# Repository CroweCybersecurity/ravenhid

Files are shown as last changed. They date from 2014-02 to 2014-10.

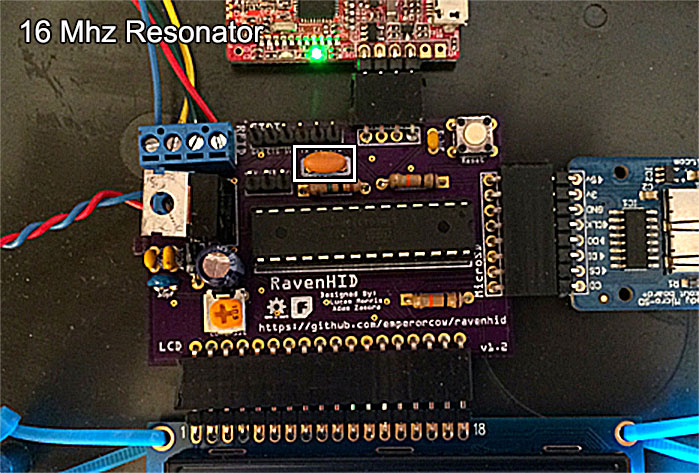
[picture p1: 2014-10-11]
wikifiles/images/crystal.jpg

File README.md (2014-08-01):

ravenhid
=

Hardware and software to run a RFID reader to harvest card information.  This is the PCB design and Arduino code that will run a RFID reader, allowing you to gather and harvest cards.  Typically, a larger reader, such as those in garages, will be more successful, allowing you to ready over a couple feet instead of inches.  The board itself is designed to be modular and support multiple methods to output harvested cards once they are read:
- Text file on a MicroSD card
- Print out to LCD
- Bluetooth Low Energy Arduino serial connection 

Each of these options are supported in code, but can be ignored on the PCB.  The PCB itself has been designed to use a pluggable module for each of these options, making it easy to ignore, install, or change out which ones you find useful.  

#### PCB Design

We used Fritzing, an open source solution, to design the hardware for the RavenHID.  If you open our file in Frizting, you'll see the design which can be changed to suit your needs.  

#### Installation and Build
So the most difficult part of this is getting the PCB created.  There are numerous methods, and you should do what works for you.  If you're interested in having the board fabbed, we've made an OSHPark project to make it easy for you!  They do great work and you'll get three copies of the board just in case you have issues!

https://www.oshpark.com/shared_projects/Kp0nErMB

Once you have your board, you'll need all of the hardware.  The following bill of materials includes everything you need.  All of the parts are labelled on the PCB and everything is through-hole components to make it easy to solder together.  Once everything is put together, you'll need to load the code on your Arduino, which will require the Arduino IDE which can be downloaded freely.  

#### Power

You'll need to get a power pack of some kind.  Personally we've been using a lithium battery pack that is used to charge external devices.  The important things to note before you buy one are: 

* It must output at least 12V, it can output up to about 24V
* It needs to use a standard DC barrel jack, make sure as many of these only output USB
* Make sure it has some sort of auto-off or power switch, as you don't want to be opening the case constantly

The RavenHID PCB doesn't consume much power, but the HID reader most certainly does.  Even with this, we bought a $50 battery pack on Amazon and have never run out of power even leaving the RavenHID on the entire day.  

#### HID Reader
We have been using the [HID MaxiProx 5375|http://www.hidglobal.com/products/readers/hid-proximity/5375] for our reader.  Its large enough to pull cards from a couple feet, it can speak the right protocol for our Arduino, and its large enough to hold all of our electronics on the inside.  Additionally, you can also turn off the beeper, and it fits nicely in several bags, allowing you to gather discreetly. 

The reader can be wired to the RavenHID directly, there is a header which will output power and data to and from the MaxiProx.  

We used the Wiegand protocol to gather data into the RavenHID, so make sure that whatever reader you get is able to support that format.  This format uses two lines, Data0 and Data1, and changes the voltage on these two lines to signal a 0 or 1 bit.  The Arduino reads these one at a time and then compiles it and identifies the card data it contains.  Arduino interrupts are used on these lines, which allows us to do some bitwise addition in the code to get all the bits.

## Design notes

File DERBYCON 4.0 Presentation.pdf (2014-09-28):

## RAVENHID: REMOTE BADGE GATHERING

Lucas Morris | @lucasjmorris
Adam Zamora | @azdmin

## About Us

### Lucas Morris

! Manager at Crowe Horwath LLP
! “Manager”, Pentester, Code Monkey

### Adam Zamora

! Senior Consultant at Crowe Horwath LLP ! Pentester, [something funny here]

## Our Plug (cont.)

Lucas Morris
=> | emperorcow@gmail.com
=> | @lucasjmorris
=> | github.com/emperorcow

Adam Zamora
=> | ninjazamo@gmail.com
=> | @azdmin

https://github.com/emperorcow/ravenhid
https://www.oshpark.com/shared_projects/Kp0nErMB

## Overview

RFID Refresher
Physical Access Control Systems Our Methodology
Mitigation and Remediation
Tools!

## Radio Frequency Identification (RFID)

Low Frequency – Used without license
! Various identification and data collection
High Frequency
! Smart Cards, product identification
Ultra-High Frequency
! Supply chain tracking, defense applications
Type | Frequency
LF - Low Frequency | 126 kHz
HF - High Frequency | 13.56 MHz
UHF - Ultra High Frequency | 433 MHz

## Physical Access Control

Low Frequency proximity encompasses 80%+ ! Education Facilities
! Financial Institutions
! Medical Facilities
! Government/Municipalities

Blank cards (T5577) cost between $0.30 – $1.00 each

## How Most Doors Work

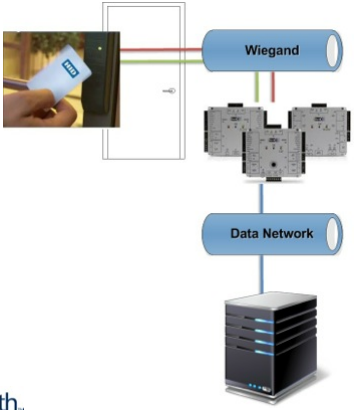
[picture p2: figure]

## How Weigand Works

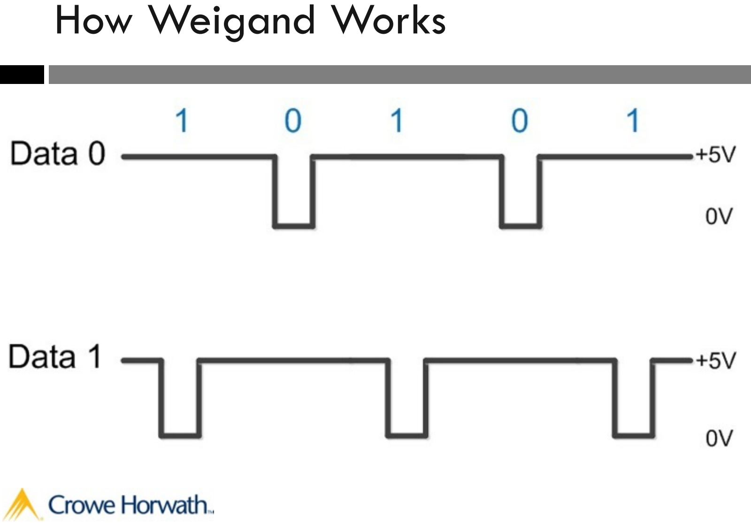
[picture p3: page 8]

## Our Methodology

Identify our targets
Shared building
! Have a lookout for reader to tail ! Find a common area
! Patience (and bathrooms!)

Clone stolen badge (Proxmark)

Brute-force sequential IDs if necessary

## Our Device

Based on several Internet designs
Lots of outputs supported (LCD, RGB LCD, BLE, SD Card)
Application for Phone management (BLE)
Through hole components for ease of assembly

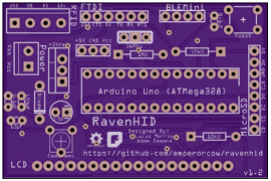
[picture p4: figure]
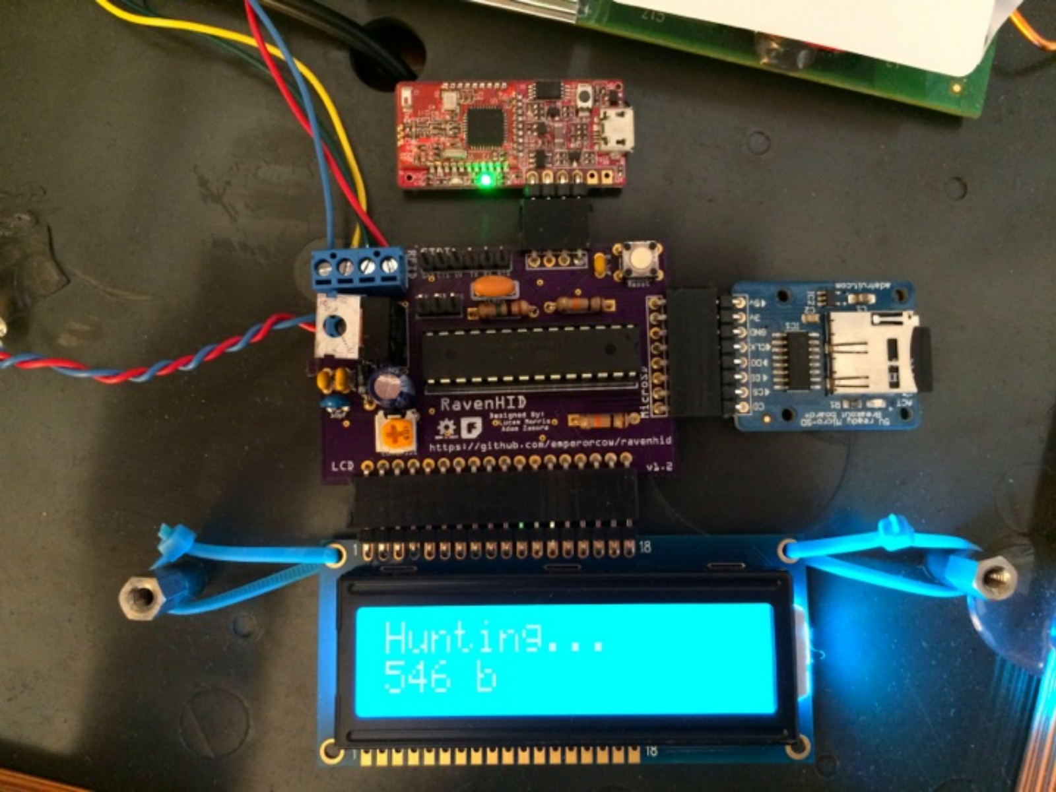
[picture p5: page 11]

11

## Our Device

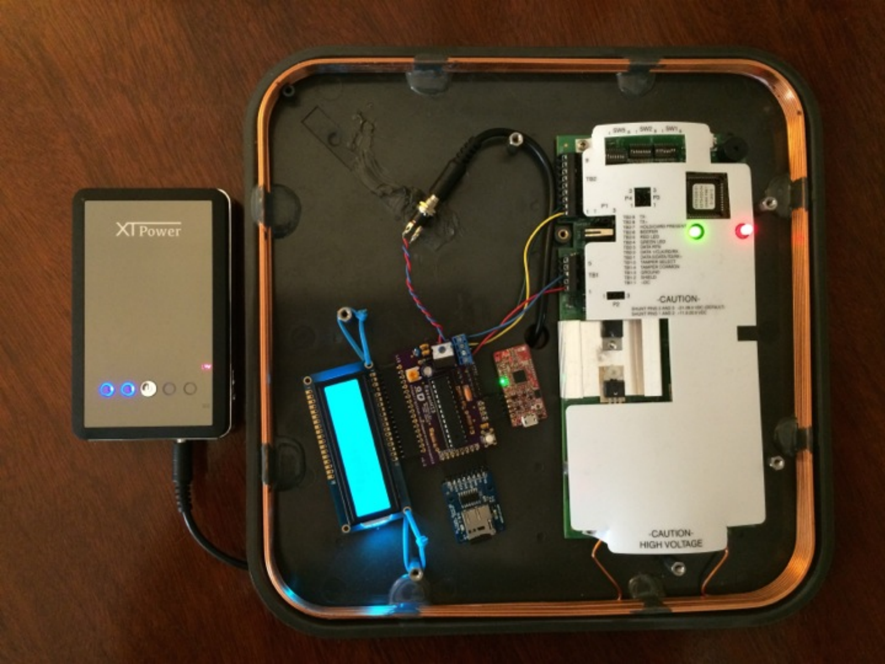
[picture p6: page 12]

12

## Demo!

## Mitigation and Remediation

Badge Protection

User Education

Multi-Factor Readers

Newer Badge Systems?

## Questions?

Lucas Morris
=> | emperorcow@gmail.com
=> | @lucasjmorris
=> | github.com/emperorcow

Adam Zamora
=> | ninjazamo@gmail.com
=> | @azdmin

https://github.com/emperorcow/ravenhid
https://www.oshpark.com/shared_projects/Kp0nErMB

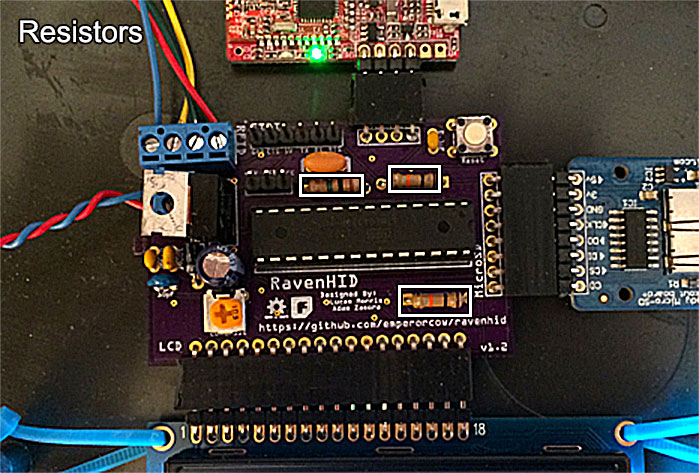
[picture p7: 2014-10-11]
wikifiles/images/resistors.jpg

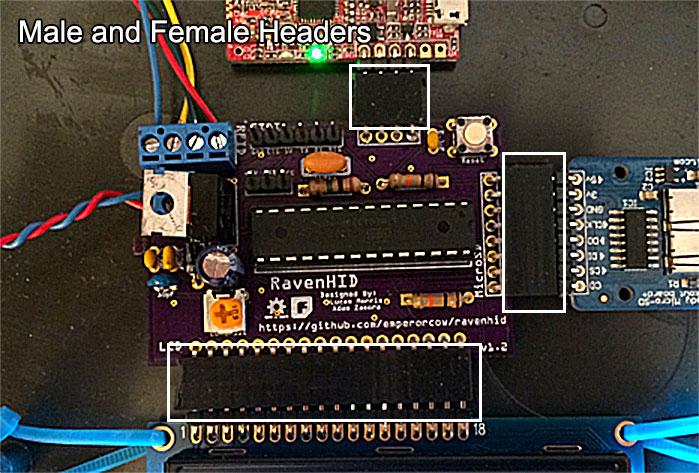
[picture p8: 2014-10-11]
wikifiles/images/rightheaders.jpg

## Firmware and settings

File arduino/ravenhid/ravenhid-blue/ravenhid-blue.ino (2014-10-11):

#include <SD.h>
#include <LiquidCrystal.h>
#include <SoftPWM.h>
#include "lcd.h"
#include "weigand.h"
#include <Arduino.h>
#include <AltSoftSerial.h>

#define LCD_BLUE A4
#define LCD_GREEN A3
#define LCD_RED A2
#define LCD_RS A0
#define LCD_ENABLE A1
#define LCD_D4 8
#define LCD_D5 7
#define LCD_D6 6
#define LCD_D7 5

#define RFID_D0 2
#define RFID_D1 3

#define SD_CS 10
 
AltSoftSerial BLEMini; 


unsigned char buf[21] = {0};
unsigned char len = 0;

Weigand w(RFID_D0, RFID_D1);
LiquidCrystal lcd(LCD_RS, LCD_ENABLE, LCD_D4, LCD_D5, LCD_D6, LCD_D7);

boolean startupError = false;

void readD0() {
  w.add0();
}

void readD1() {
  w.add1();
}

void setup() {
  Serial.begin(57600);
  Serial.println(F("[*] Setting up..."));
  
  BLEMini.begin(57600);
  
  lcd.begin(16, 2);
  lcdClear();
  lcdWriteLine1("Starting up...");
   
  pinMode(A2, OUTPUT);
  pinMode(A3, OUTPUT);
  pinMode(A4, OUTPUT);
  SoftPWMBegin();

  attachInterrupt(0, readD0, FALLING);
  attachInterrupt(1, readD1, FALLING);

  w.resetdata();

  pinMode(SD_CS, OUTPUT);
  if(!SD.begin(SD_CS)) {
    Serial.println("[!] SD card failed or not present.");
    setLCDColor(error);
    lcdClear();
    lcdWriteLine1("No SD Card Found");
    startupError = true;
  }
  
  if(startupError) {
    delay(5000); //Give our users a chance to read the error instead of coloring the rainbow.
  } else {
    lcdRainbow(); // Wait for a little bit to let the data lines settle. Since we've got time, lets show off.
  }
  
  lcdClear();
  Serial.println("[*] Setup complete.");
}

void loop() {
  if(w.loop()) {
     Serial.println("");
     setLCDColor(green);
     lcdWriteCard(w.getcount(), w.parsecard());
     sdWriteCard();
	 sendBluetooth();
	 
     delay(2000);
     w.resetdata();
     lcdClear();
   } else {
     setLCDColor(info);
     lcdWriteLine1("Hunting...");
     lcd.setCursor(0,1);
     lcd.print(freeRam());
     lcd.print(" b");
   }
}

void sdWriteCard() {
  File csvFile = SD.open("cards.csv", FILE_WRITE);
  if(csvFile) {
    uint64_t card = w.parsecard();
    csvFile.print(w.getcount());
    csvFile.print(",");
    csvFile.print(card, BIN);
    csvFile.print(",");
    csvFile.print(card, HEX);
    csvFile.println("");
    csvFile.close();
    
    Serial.print("[*] Got data: '");
    Serial.print(w.getcount());
    Serial.print(",");
    Serial.print(card, BIN);
    Serial.print(",");
    Serial.print(card, HX);
    Serial.println("'");
  } else {
    lcdClear();
    setLCDColor(error);
    lcdWriteLine1("Error writing.");
    lcdWriteLine2("to file.");
  }
}

void sendBluetooth() {
	if (BLEMini.available()) {
		char buff[21];
		// not sure which of the two lines below will work
		sprintf(buff, "%" PRIu64, card);
		sprintf (buff, sizeof(buf)-1, "%llu", (unsigned long long) card);
		
		len = sizeof(buff);
		BLEMini.write();	
		for (int i = 0; i < len; i++)
         BLEMini.write(buff[i]);
      len = 0;
	}
}

extern uint8_t* __brkval;
extern uint8_t __heap_start;
int freeRam () {
  int v;
  return (int) &v - (__brkval == 0 ? (int) &__heap_start : (int) __brkval);
}

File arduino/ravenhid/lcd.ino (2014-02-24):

 void setLCDColor(lcdstatus s) {
  switch(s) {
  case error: 
    lcdWriteColor(0xff, 0x00, 0x00);
    break;   
  case warning: 
    lcdWriteColor(0xff, 0x22, 0x00);
    break;    
  case info: 
    lcdWriteColor(0x00, 0xff, 0xff);
    break;    
  case green:
    lcdWriteColor(0x00, 0xff, 0x00);
    break;
  default: 
    lcdWriteColor(0xff, 0xff, 0xff);
  }
}

void lcdRainbow() {
  unsigned int rgbColor[3];
   
  // Start off with red.
  rgbColor[0] = 255;
  rgbColor[1] = 0;
  rgbColor[2] = 0;
   
  // Choose the colours to increment and decrement.
  for (int decColor = 0; decColor < 3; decColor += 1) {
    int incColor = decColor == 2 ? 0 : decColor + 1;
     
    // cross-fade the two colours.
    for(int i = 0; i < 255; i += 1) {
      rgbColor[decColor] -= 1;
      rgbColor[incColor] += 1;
      SoftPWMSet(LCD_RED, rgbColor[0]); 
      SoftPWMSet(LCD_GREEN, rgbColor[1]);
      SoftPWMSet(LCD_BLUE, rgbColor[2]);
      delay(5);
    }
  }
}


void lcdWriteColor(int r, int g, int b) {
  SoftPWMSet(LCD_RED, map(r, 0, 255, 255, 0)); 
  SoftPWMSet(LCD_GREEN, map(g, 0, 255, 255, 0));
  SoftPWMSet(LCD_BLUE, map(b, 0, 255, 255, 0));
}

void lcdWriteLine1(char text[]) {
  lcd.setCursor(0, 0);
  lcd.print(text); 
}

void lcdWriteLine2(char text[]) {
  lcd.setCursor(0, 1);
  lcd.print(text); 
}

void lcdWriteCard(unsigned int bits, uint64_t card) {
  lcdClear();
  
  lcd.setCursor(0, 0); 
  lcd.print(F("Size: "));
  lcd.print(bits);
  
  lcd.setCursor(0, 1);
  lcd.print(card, HEX);
}

void lcdClear() {
  lcd.clear(); 
}

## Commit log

2013-12-12 Moved Fritzing to a directory
    [ravenhid.fzz]
2014-02-04 Updated PCB
    Fixed hole sizes from 1.0 board and made labels better.
    [ravenhid.fzz]
2014-02-19 Initial Arduino Breadboard Code
2014-02-22 Fixed weigand math, added test case for weigand26
    [lcd.ino, ravenhid.ino, weigand.cpp]
2014-02-24 PCB fixes
    Changed Weigand pins to D2 and D3 to allow for attachinterrupt
    [ravenhid.fzz]
2014-02-24 Beta code final
    Updated code to add SD card output, fixes to startup, and a little flair
    while waiting on weigand to settle.
    [lcd.ino, ravenhid.ino, weigand.cpp]
2014-02-24 Updates to PCB including fixing some overlapping traces
    [ravenhid.fzz]
2014-03-20 Board updates from v1.1 build
    Changed spaces on board to hold real pins as the library one drills were
    too small. Changed power from barrel jack to screw terminals as jack is
    elsewhere in the case.
    [ravenhid.fzz]
2014-03-28 Minor PCB changes
    Fixed a crossed PCB wire segment
    [ravenhid.fzz]
2014-03-28 Added ground fill
    This PCB is being sent to fab
    [ravenhid.fzz]
